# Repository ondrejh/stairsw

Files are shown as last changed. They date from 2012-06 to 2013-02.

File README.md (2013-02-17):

Staircase switch project using launchpad, mspgcc and interrupts

Author: Ondrej Hejda
Date: 21.6.2012

Description:
Staircase switch (switching light from multiple points) with button input
and led indication.
Output changes when button is pressed.
Leds (or 2color led) are/is smoothly regulated (changing color with diming efect).
Project is used as example application for mspgcc compiler, launchpad and interrupts.
Code::Blocks IDE files are also included (CB's using external Makefile).

Files:
    main.c                      .. source code
    Makefile                    .. makefile (for mspgcc)
    project.cbp, project.layout .. Code::Blocks project files

Revision 17.2.2013: Smaller MCU, door switch and timeout feature.
Project was a bit repurposed to normal light switch used in storeroom. Therefor I've added door switch (for automatic light switching) and automatic switching off timeout. I've also added HW files with pcb designed for the purpose.

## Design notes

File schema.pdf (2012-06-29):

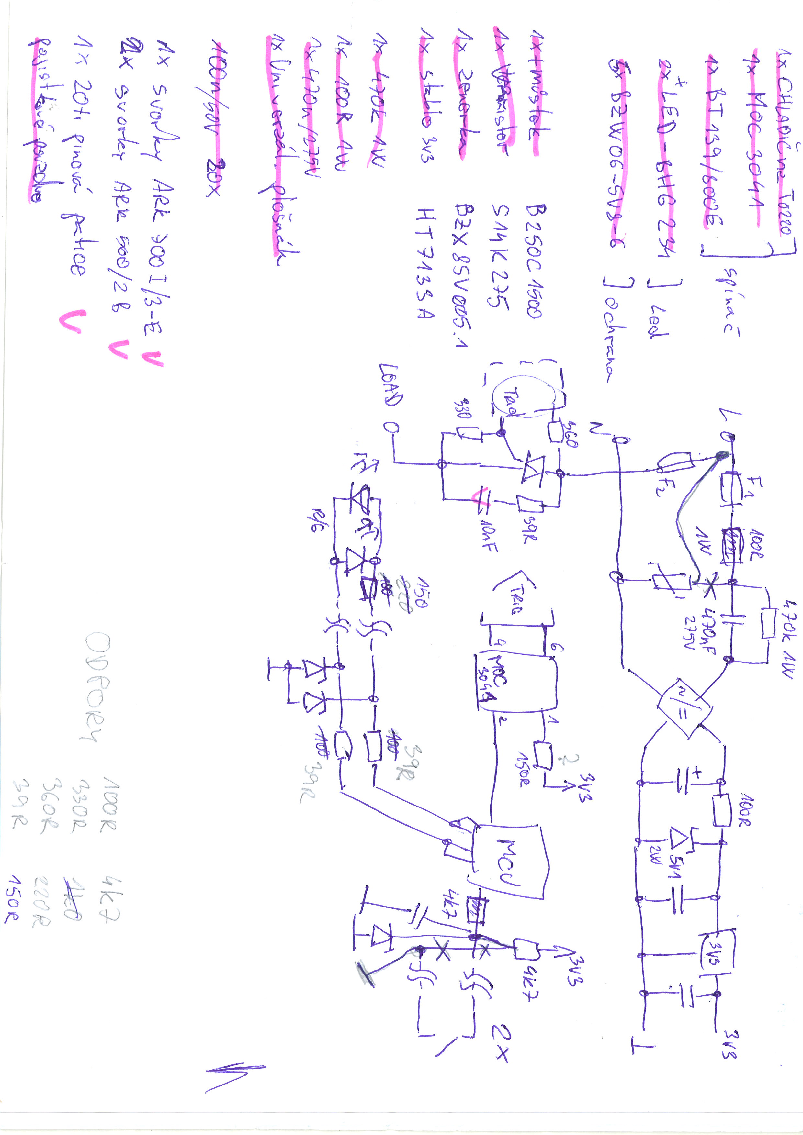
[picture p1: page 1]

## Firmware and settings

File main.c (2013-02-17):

//******************************************************************************
//
// Launchpad staircase switch application
//
// author: Ondrej Hejda
// date:   21.6.2012
//
// description:
//
//	 Swapping output state (OUT_ON/OUT_OFF) when pushbutton pressed (BTN_DOWN).
//   Output state is indicated by red and green LEDs (LED_RED..,LED_GREEN..),
//   or double led (red/green).
//   Input button is filtered (10 x 5ms). LEDs are smoothed (5 levels).
//
// used TI demos:
//
//   MSP430G2xx3 Demo - P1 Interrupt from LPM4 with Internal Pull-up
//   MSP430G2xx3 Demo - Timer_A, Toggle P1.0, CCR0 Cont. Mode ISR, DCO SMCLK
//
// hw: two variants of MCU supported (Launchpad equipment)
//   MSP430G2553, MSP430G2452 .. select by macro in include section
//
//                MSP4302x5x
//             -----------------
//         /|\|              XIN|-
//          | |                 |
//          --|RST          XOUT|-
//            |                 |
//            |    P1.0 (P2.3,4)|--> RED LED (active high)   |
//            |      P1.6 (P2.5)|--> GREEN LED (active high) | or R/G led two/w
//            |                 |
//            |             P1.3|<-- BUTTON WITH PULLUP (active low)
//            |                 |
//            |           P2.1,2|--> OUT (active low)
//            |                 |
//
// 2012.06.29: output port connected
//             leds pin and output pin doubled (tripled) to get more current
//
// 2013.02.17: 14pin mcu MSP430G2201
//
//                MSP4302201
//             -----------------
//         /|\|              XIN|-
//          | |                 |
//          --|RST          XOUT|-
//            |                 |
//            |           P1.0,1|--> RED LED (active high)   |
//            |           P1.2,3|--> GREEN LED (active high) | or R/G led two/w
//            |                 |
//            |             P1.4|<-- BUTTON WITH PULLUP (active low)
//            |             P1.5|<-- DOOR SWITCH WITH PULLUP (active low)
//            |                 |
//            |           P1.6,7|--> OUT (active low)
//            |                 |
//
//******************************************************************************


/// include section

//#define MSP430G2553
//#define MSP430G2452
#define MSP430G2201

#ifdef MSP430G2452
	#include "msp430g2452.h"
#endif
#ifdef MSP430G2201
	#include "msp430g2201.h"
#endif
#ifdef MSP430G2553
	#include "msp430g2553.h"
#endif

#include "stdbool.h"


/// feature selections

// use door switch if defined:
#define DOOR_SWITCH

// use timeout timer if not zero:
#define AUTO_OFF_TIMEOUT 30000 //2.5min (5ms tick)


/// port pin assignment section

#ifndef MSP430G2201
// 20 pin MCUs

// board (leds, button)
#define LED_INIT() {P1DIR|=0x41;P1OUT&=~0x41;P2DIR|=0x38;P2OUT&=~0x38;}
#define LED_RED_ON() {P1OUT|=0x01;P2OUT|=0x18;}
#define LED_RED_OFF() {P1OUT&=~0x01;P2OUT&=~0x18;}
#define LED_GREEN_ON() {P1OUT|=0x40;P2OUT|=0x20;}
#define LED_GREEN_OFF() {P1OUT&=~0x40;P2OUT&=~0x20;}

#define BTN_INIT() {P1DIR&=~0x08;P1REN|=0x08;P1OUT|=0x08}
#define BTN_DOWN ((P1IN&0x08)==0)
#define OUT_INIT() {P2DIR|=0x06;P2OUT|=0x06;}
#define OUT_ON() {P2OUT&=~0x06;}
#define OUT_OFF() {P2OUT|=0x06;}

#ifdef DOOR_SWITCH
#define DSWITCH_INIT() {}
#define DSWITCH_CLOSED (true)
#endif

#else
// 14 pin MCUs

// board (leds, button)
#define LED_INIT() {P1DIR|=0x41;P1OUT&=~0x41;}
#define LED_RED_ON() {P1OUT|=0x03;}
#define LED_RED_OFF() {P1OUT&=~0x03;}
#define LED_GREEN_ON() {P1OUT|=0x0C;}
#define LED_GREEN_OFF() {P1OUT&=~0x0C;}

#define BTN_INIT() {P1DIR&=~0x10;P1REN|=0x10;P1OUT|=0x10;}
#define BTN_DOWN ((P1IN&0x10)==0)
#define OUT_INIT() {P1DIR|=0xC0;P1OUT|=0xC0;}
#define OUT_ON() {P1OUT&=~0xC0;}
#define OUT_OFF() {P1OUT|=0xC0;}

#ifdef DOOR_SWITCH
#define DSWITCH_INIT() {P1DIR&=~0x20;P1REN|=0x20;P1OUT|=0x20;}
#define DSWITCH_CLOSED ((P1IN&0x20)==0)
#endif

#endif


/// other definitions

// time base 5ms (5000 ticks / 1MHz)
#define Timer_Const 5000
#define Led_PWM_Levels 5
#define Btn_Filter 10
#define Btn_Filter_MAX 100


/// local functions section

// timer initialization
void timer_init(void)
{
	CCTL0 = CCIE;				// CCR0 interrupt enabled
	CCR0 = Timer_Const;
	TACTL = TASSEL_2 + MC_2;	// SMCLK, contmode
}

// hw depended initialization
void board_init(void)
{
	// oscillator
	BCSCTL1 = CALBC1_1MHZ;		// Set DCO
	DCOCTL = CALDCO_1MHZ;

	// unused pins (all but future init)
	P1OUT = 0x00; P1DIR = 0xFF;
	P2OUT = 0x00; P2DIR = 0xFF;
	#ifdef MSP430G2553
	P3OUT = 0x00; P3DIR = 0xFF;
	#endif

	LED_INIT(); // leds
	BTN_INIT(); // button
	OUT_INIT(); // output
	#ifdef DOOR_SWITCH
	DSWITCH_INIT();
	#endif
}


/// main programm section

// main program body
int main(void)
{
	WDTCTL = WDTPW + WDTHOLD;	// Stop WDT

	board_init();
	timer_init();

	__bis_SR_register(LPM0_bits + GIE);		// Enter LPM0, interrupts enabled

    return -1;
}


/// interrupt routines

// Timer A0 interrupt service routine (5ms)
#pragma vector=TIMER0_A0_VECTOR
__interrupt void Timer_A (void)
{
	static unsigned int OnCnt=0, OffCnt=0; // on and off button state counter
	static unsigned int sw_seqv = 0; // switch sequential pointer
	static bool out_st = false; // output state (on/off)

	#if AUTO_OFF_TIMEOUT!=0
	static unsigned int AutoOffTimer = 0;
	#endif

	#ifdef DOOR_SWITCH
	static unsigned int DSOnCnt=0, DSOffCnt=0; // on and off button state counter

	// door switch reading
	if (DSWITCH_CLOSED)
	{
		if (DSOnCnt<Btn_Filter_MAX) DSOnCnt++;
		DSOffCnt=0;
	}
	else
	{
		if (DSOffCnt<Btn_Filter_MAX) DSOffCnt++;
		DSOnCnt=0;
	}
	#endif

	// button reading
	if (BTN_DOWN)
	{
		if (OnCnt<Btn_Filter_MAX) OnCnt++;
		OffCnt=0;
	}
	else
	{
		if (OffCnt<Btn_Filter_MAX) OffCnt++;
		OnCnt=0;
	}

	// button sequential
	switch (sw_seqv)
	{
		case 0: // Off (after reset) .. wait button
            #ifdef DOOR_SWITCH
			if (DSOffCnt==Btn_Filter)
			{
			    OUT_ON();
			    out_st=true;
			    #if AUTO_OFF_TIMEOUT!=0
			    AutoOffTimer=AUTO_OFF_TIMEOUT;
			    #endif
			    sw_seqv+=2;
			}
			#endif
			if (OnCnt==Btn_Filter)
			{
				OUT_ON();
				out_st=true;
			    #if AUTO_OFF_TIMEOUT!=0
			    AutoOffTimer=AUTO_OFF_TIMEOUT;
			    #endif
				sw_seqv++;
			}
			break;
		case 1: // Wait button release
			if (OffCnt==Btn_Filter) sw_seqv++;
			break;
		case 2: // On .. wait button
            #if AUTO_OFF_TIMEOUT!=0
            if (AutoOffTimer>0) AutoOffTimer--;
            else
            {
                OUT_OFF();
                out_st=false;
                sw_seqv=0;
            }
            #endif
            #ifdef DOOR_SWITCH
			if (DSOnCnt==Btn_Filter)
			{
			    OUT_OFF();
			    out_st=false;
			    sw_seqv=0;
			}
			#endif
			if (OnCnt==Btn_Filter)
			{
				OUT_OFF();
				out_st=false;
				sw_seqv++;
			}
			break;
		case 3: // Wait button release
			if (OffCnt==Btn_Filter) sw_seqv=0;
			break;
		default:
			sw_seqv=0;
			break;
	}

	// led pwm
	static unsigned int led_pwm_cnt=0; // led pwm counter
	static int led_red_pwm=0, led_green_pwm=0; // led pwm actual value
	if (led_red_pwm>led_pwm_cnt) LED_RED_ON()
	else LED_RED_OFF();
	if (led_green_pwm>led_pwm_cnt) LED_GREEN_ON()
	else LED_GREEN_OFF();
	led_pwm_cnt++;
	if (led_pwm_cnt>=Led_PWM_Levels)
	{
		led_pwm_cnt=0;

		// led sequential
		static unsigned int led_seqv = 0; // led sequential pointer
		switch (led_seqv)
		{
			case 0: // leds off
				if (out_st) led_seqv=4;
				else led_seqv=1;
				break;
			case 1: // red led goes on
				led_red_pwm++;
				if (led_red_pwm>=Led_PWM_Levels)
				{
					led_red_pwm=Led_PWM_Levels;
					led_seqv++;
				}
				break;
			case 2: // red led is on
				if (out_st) led_seqv++;
				break;
			case 3: // red led goes of
				led_red_pwm--;
				if (led_red_pwm<=0)
				{
					led_red_pwm=0;
					led_seqv=0;
				}
				break;
			case 4: // green led goes on
				led_green_pwm++;
				if (led_green_pwm>=Led_PWM_Levels)
				{
					led_green_pwm=Led_PWM_Levels;
					led_seqv++;
				}
				break;
			case 5: // green led is on
				if (!out_st) led_seqv++;
				break;
			case 6: // green led goes off
				led_green_pwm--;
				if (led_green_pwm<=0)
				{
					led_green_pwm=0;
					led_seqv=0;
				}
				break;
			default:
				led_green_pwm=0;
				led_red_pwm=0;
				led_seqv=0;
				break;
		}
	}

	CCR0 += Timer_Const;		// Add Offset to CCR0
}

// unused interrupts handler
#ifdef MSP430G2553
#pragma vector=	ADC10_VECTOR,\
				COMPARATORA_VECTOR,\
				NMI_VECTOR,\
				PORT1_VECTOR,\
				PORT2_VECTOR,\
				TIMER0_A1_VECTOR,\
				TIMER1_A0_VECTOR,\
				TIMER1_A1_VECTOR,\
				USCIAB0RX_VECTOR,\
				USCIAB0TX_VECTOR,\
				WDT_VECTOR
#endif
#ifdef MSP430G2452
#pragma vector=	ADC10_VECTOR,\
				COMPARATORA_VECTOR,\
				NMI_VECTOR,\
				PORT1_VECTOR,\
				PORT2_VECTOR,\
				TIMER0_A1_VECTOR,\
				WDT_VECTOR
#endif
#ifdef MSP430G2201
#pragma vector= NMI_VECTOR,\
                PORT1_VECTOR,\
				PORT2_VECTOR,\
				TIMER0_A1_VECTOR,\
                WDT_VECTOR
#endif
__interrupt void ISR_trap(void)
{
  // the following will cause an access violation which results in a PUC reset
  WDTCTL = 0;
}

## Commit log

2012-06-29 output connected, led and out pins doubled (tripled)
2012-06-29 schematic draft
2013-02-17 door switch feature
2013-02-17 auto switching off timeout feature
2013-02-17 part values according to assembly
    [hw.brd, hw.sch]
2013-02-18 part values (according to asembly)
    [hw.brd, hw.sch]
2013-02-20 eagle files repaired (digged from the previous commit and updated)
    [hw.brd, hw.sch]
